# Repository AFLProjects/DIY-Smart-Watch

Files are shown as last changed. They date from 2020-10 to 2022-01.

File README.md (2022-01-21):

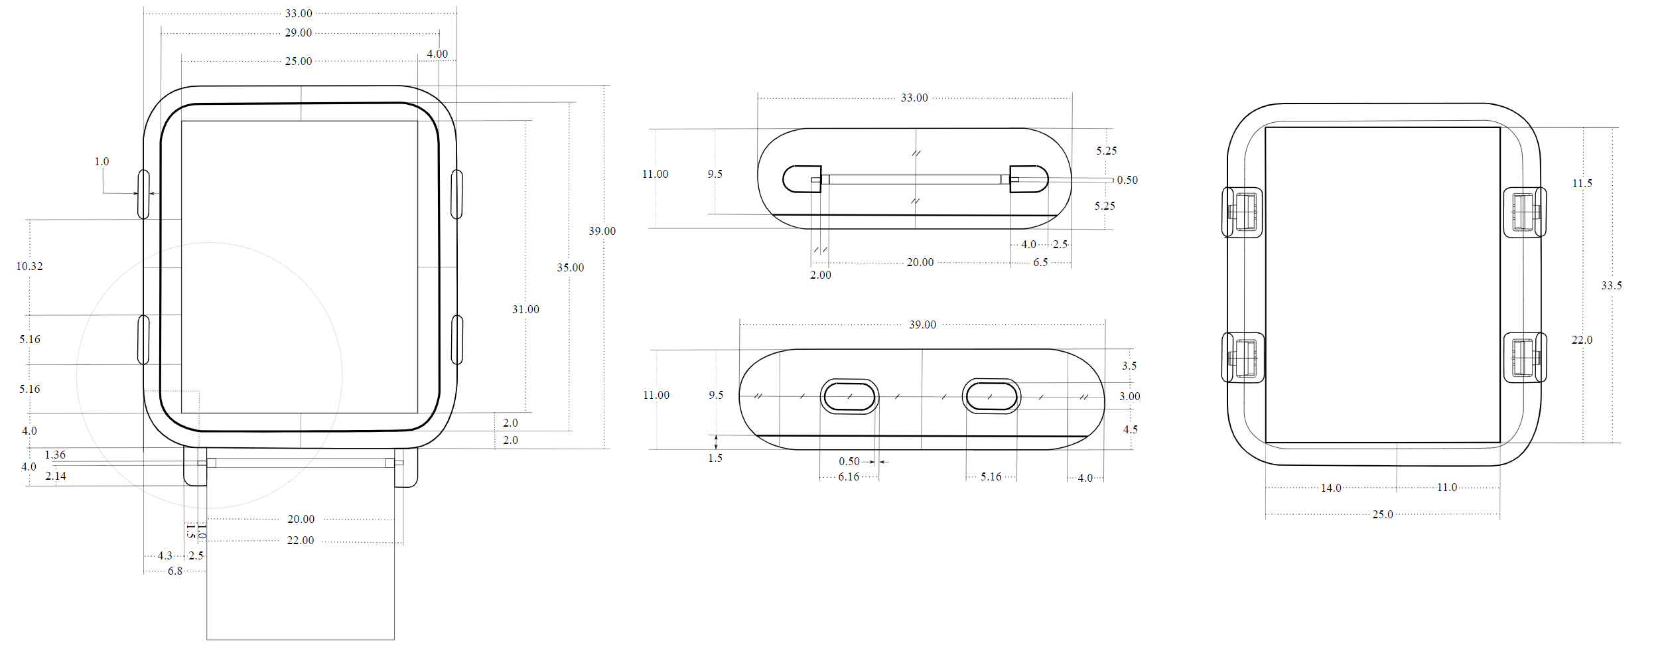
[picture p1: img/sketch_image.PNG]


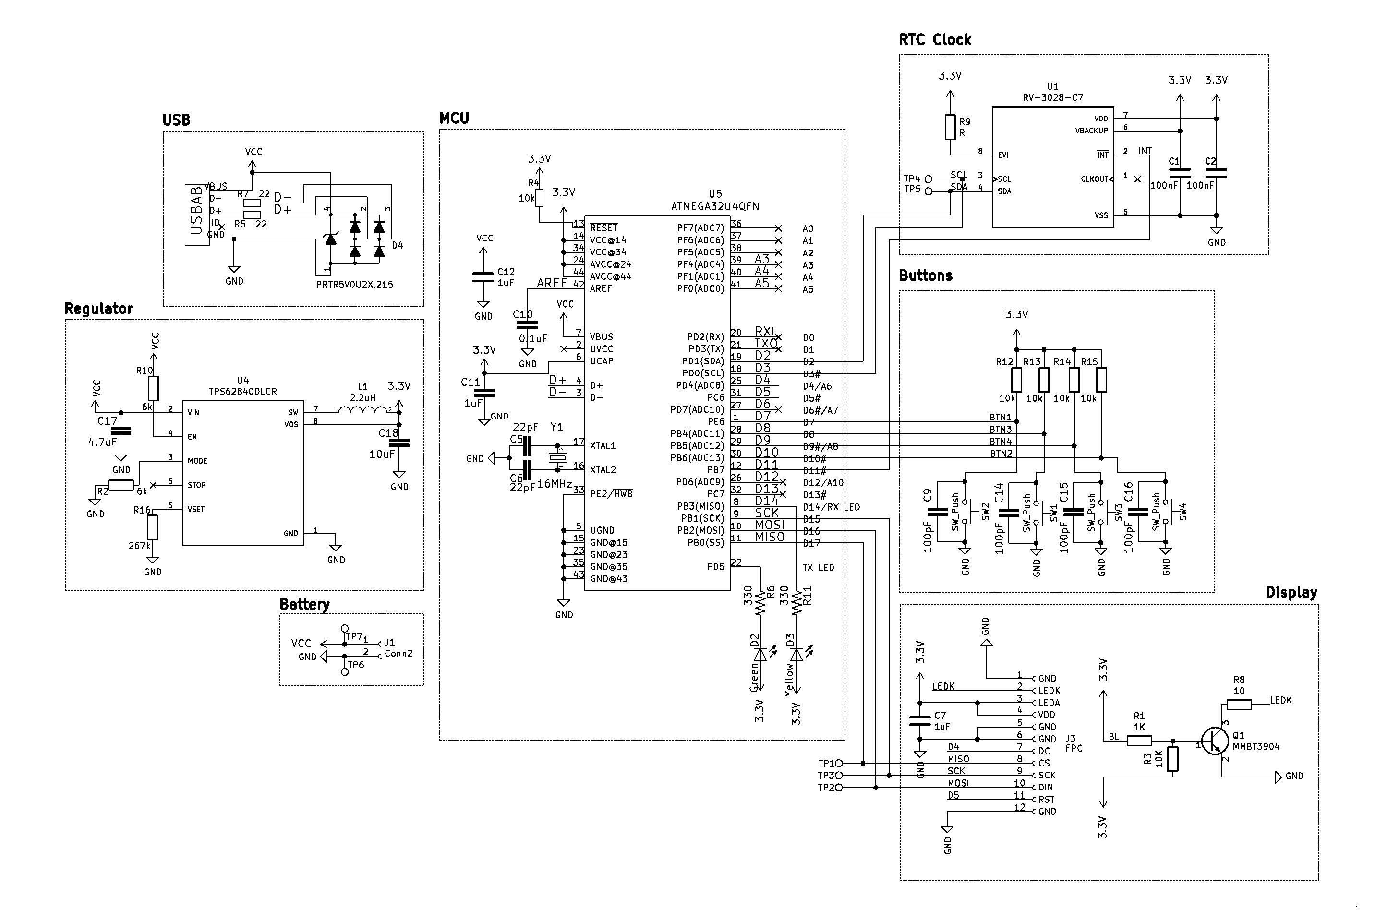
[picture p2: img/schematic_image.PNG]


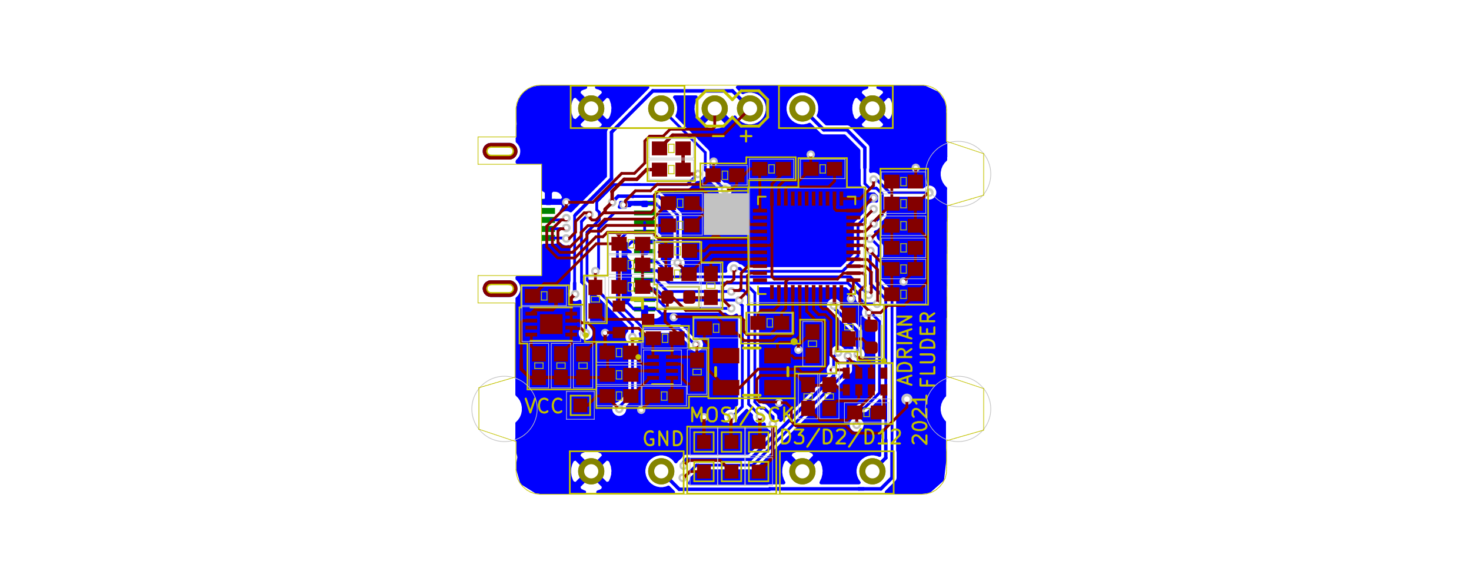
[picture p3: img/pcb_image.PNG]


Project Overview
========

The project is an MCU based smartwatch. The MCU which is used is the [ATMEGA32U4](http://ww1.microchip.com/downloads/en/devicedoc/atmel-7766-8-bit-avr-atmega16u4-32u4_datasheet.pdf). The whole project is powered with the [3.7V 380mAh LQ-S1](https://i.ibb.co/z8Tqzwt/Capture.png) lithium battery.
I am also using an TFT 240 x 240 IPS [ST7789](https://www.rhydolabz.com/documents/33/ST7789.pdf) display with [SPI](https://fr.wikipedia.org/wiki/Serial_Peripheral_Interface). And the [RV-3028-C7](https://www.mouser.fr/datasheet/2/530/RV-3028-C7-1524919.pdf) Extreme Low Power RTC Module with [I2C](https://fr.wikipedia.org/wiki/I2C). In future revisions, an accelerometer will be added.

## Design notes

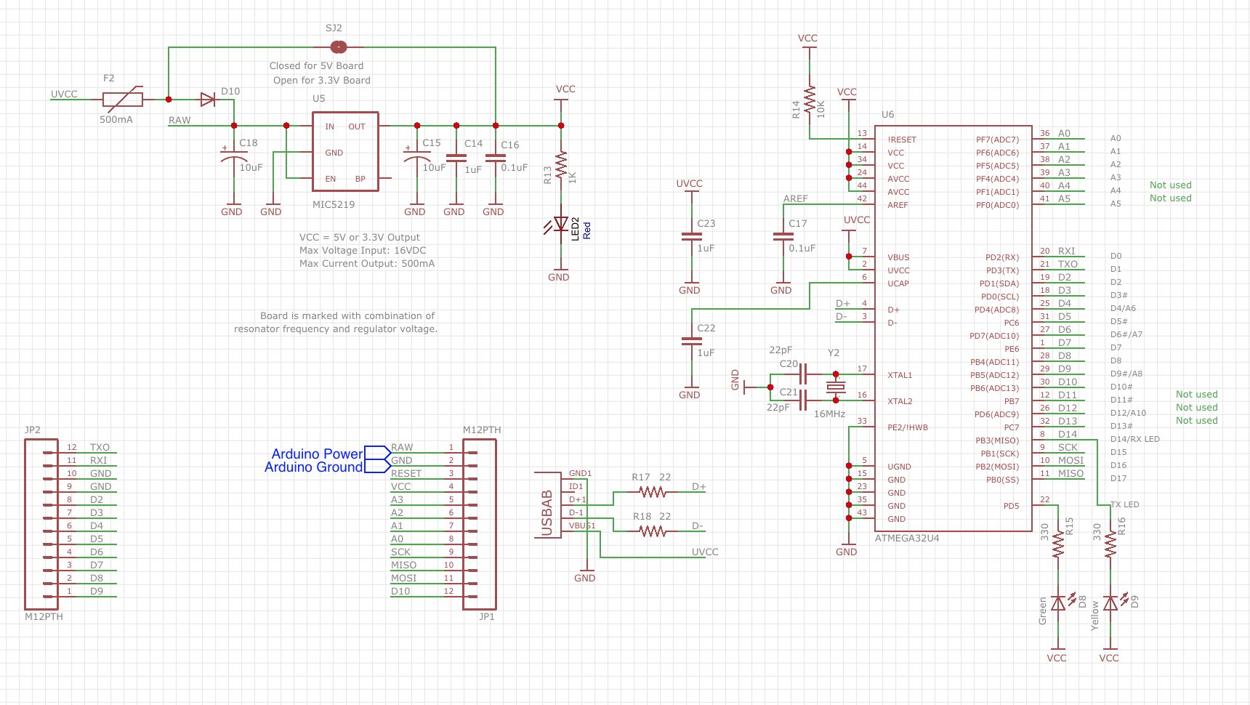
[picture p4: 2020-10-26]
Hardware/Datasheets/ATMEGA32U4/ref/schematic.png

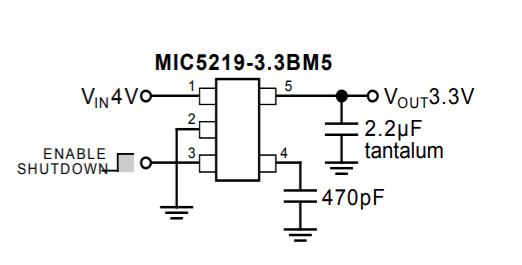
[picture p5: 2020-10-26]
Hardware/Datasheets/MIC5219/ref/schematic.PNG

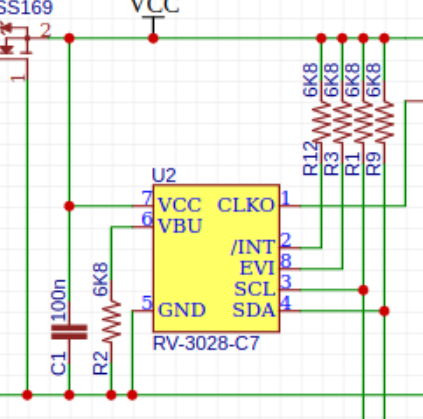
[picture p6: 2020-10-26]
Hardware/Datasheets/RV-3028-C7/ref/schematic.PNG

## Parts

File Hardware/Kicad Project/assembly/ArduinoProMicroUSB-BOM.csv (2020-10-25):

Designator | Quantity | Value | Footprint | LCSC Part #
C3, C7, C11, C12, | 4 | 1uF | Capacitor_SMD:C_0402_1005Metric | C52923
C4, C10, | 2 | 0.1uF | Capacitor_SMD:C_0402_1005Metric | C1525
C5, C6, | 2 | 22pF | Capacitor_SMD:C_0402_1005Metric | C1555
C8, C9, | 2 | 100nF | Capacitor_SMD:C_0402_1005Metric | C1525
D1, | 1 | DIODESOD | Diode_SMD:D_SOD-123 | C8598
D2, | 1 | Green | Diode_SMD:D_0805_2012Metric | C2296
D3, | 1 | Yellow | Diode_SMD:D_0805_2012Metric | C2296
D4, | 1 | D | Diode_SMD:D_0805_2012Metric | C2296
D5, | 1 | LED | Diode_SMD:D_0805_2012Metric | C2296
F1, | 1 | 500mA | Fuse:Fuse_1812_4532Metric | C151168
LED1, | 1 | Red | Diode_SMD:D_0805_2012Metric | C2296
Q1, | 1 | MMBT3904 | Downloads:SOT23-3 | C20526
R1, R2, | 2 | 1K | Resistor_SMD:R_0603_1608Metric | C21190
R3, | 1 | 10K | Resistor_SMD:R_0603_1608Metric | C25804
R4, R12, R13, R14, R15, | 5 | 10k | Resistor_SMD:R_0603_1608Metric | C25804
R5, R7, | 2 | 22 | Resistor_SMD:R_0603_1608Metric | C23345
R6, R10, R11, | 3 | 330 | Resistor_SMD:R_0603_1608Metric | C23138
R8, | 1 | 10 | Resistor_SMD:R_0603_1608Metric | C22859
R9, | 1 | 200 | Resistor_SMD:R_0603_1608Metric | C8218
RN1, RN2, | 2 | R_Pack04 | Resistor_SMD:R_Array_Concave_4x0603 | C66697
U1, | 1 | DS3231M | Package_SO:SOIC-16W_7.5x10.3mm_P1.27mm | C37663
U2, | 1 | MIC5219 | Downloads:SOT23-5 | C145689
U5, | 1 | ATMEGA32U4QFN | Package_QFP:TQFP-44_10x10mm_P0.8mm | C44854
Y1, | 1 | 16MHz | Downloads:CRYSTAL-SMD-5X3.2-4PAD | C16171

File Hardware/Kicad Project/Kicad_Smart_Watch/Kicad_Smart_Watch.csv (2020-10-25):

Source: | F:\Kicad\screentest1\ArduinoProMicroUSB\ArduinoProMicroUSB.sch
Date: | 8/30/2020 4:58:59 PM
Tool: | Eeschema (5.1.6)-1
Generator: | C:\Program Files\KiCad\bin\scripting\plugins/bom_csv_grouped_by_value_with_fp.py
Component Count: | 50
Ref | Qnty | Value | Cmp name | Footprint | Description | Vendor
C1, C2, | 2 | 10uF | CAP_POL1206 | Capacitors:EIA3216
C3, C7, C11, C12, | 4 | 1uF | C | Capacitor_SMD:C_0402_1005Metric | Unpolarized capacitor
C4, C10, | 2 | 0.1uF | CAP0603-CAP | Capacitor_SMD:C_0402_1005Metric
C5, C6, | 2 | 22pF | CAP0603-CAP | Capacitor_SMD:C_0402_1005Metric
C8, C9, | 2 | 100nF | C | Capacitor_SMD:C_0402_1005Metric | Unpolarized capacitor
D1, | 1 | DIODESOD | DIODESOD | Diode_SMD:D_SOD-123
D2, | 1 | Green | LED0603 | Diode_SMD:D_0805_2012Metric
D3, | 1 | Yellow | LED0603 | Diode_SMD:D_0805_2012Metric
D4, | 1 | D | D | Diode_SMD:D_0805_2012Metric | Diode
D5, | 1 | LED | LED | Diode_SMD:D_0805_2012Metric | Light emitting diode
F1, | 1 | 500mA | Fuse_Small | Fuse:Fuse_1812_4532Metric | Fuse, small symbol
J1, | 1 | Battery | Conn_01x02_Female | Connector_PinSocket_2.54mm:PinSocket_1x02_P2.54mm_Vertical | Generic connector, single row, 01x02, script generated (kicad-library-utils/schlib/autogen/connector/)
J3, | 1 | Display FPC | Conn_01x12_Female | Downloads:bearlcd12pin | Generic connector, single row, 01x12, script generated (kicad-library-utils/schlib/autogen/connector/)
LED1, | 1 | Red | LED0603 | Diode_SMD:D_0805_2012Metric
Q1, | 1 | MMBT3904 | MMBT3904 | Downloads:SOT23-3 | 0.2A Ic, 40V Vce, Small Signal NPN Transistor, SOT-23
R1, R2, | 2 | 1K | RESISTOR0603-RES | Resistor_SMD:R_0603_1608Metric
R3, | 1 | 10K | R | Resistor_SMD:R_0603_1608Metric | Resistor
R4, R12, R13, R14, R15, | 5 | 10k | R | Resistor_SMD:R_0603_1608Metric | Resistor
R5, R7, | 2 | 22 | R_Small | Resistor_SMD:R_0603_1608Metric | Resistor, small symbol
R6, R10, R11, | 3 | 330 | RESISTOR0603-RES | Resistor_SMD:R_0603_1608Metric
R8, | 1 | 10 | R | Resistor_SMD:R_0603_1608Metric | Resistor
R9, | 1 | 200 | R | Resistor_SMD:R_0603_1608Metric | Resistor
RN1, RN2, | 2 | R_Pack04 | R_Pack04 | Resistor_SMD:R_Array_Concave_4x0603 | 4 resistor network, parallel topology
SJ1, | 1 | Closed for 5V Board | SOLDERJUMPERNC | Downloads:Jumper
SW1, SW2, SW3, SW4, | 4 | SW_Push | SW_Push | Connector_PinSocket_2.54mm:PinSocket_1x02_P2.54mm_Vertical | Push button switch, generic, two pins
U1, | 1 | DS3231M | DS3231M | Package_SO:SOIC-16W_7.5x10.3mm_P1.27mm | Extremely Accurate I2C-Integrated RTC/TCXO/Crystal SOIC-16
U2, | 1 | MIC5219 | V_REG_LDOSMD | Downloads:SOT23-5
U3, | 1 | USB-AB | USB-AB | Connectors:USB-AB-MICRO-SMD
U4, | 1 | AT24CS32-SSHM | AT24CS32-SSHM | Package_SO:SOIC-8_3.9x4.9mm_P1.27mm | I2C Serial EEPROM, 32Kb (4096x8) with Unique Serial Number, SO8
U5, | 1 | ATMEGA32U4QFN | ATMEGA32U4QFN | Package_QFP:TQFP-44_10x10mm_P0.8mm
Y1, | 1 | 16MHz | CRYSTAL5X3 | Downloads:CRYSTAL-SMD-5X3.2-4PAD

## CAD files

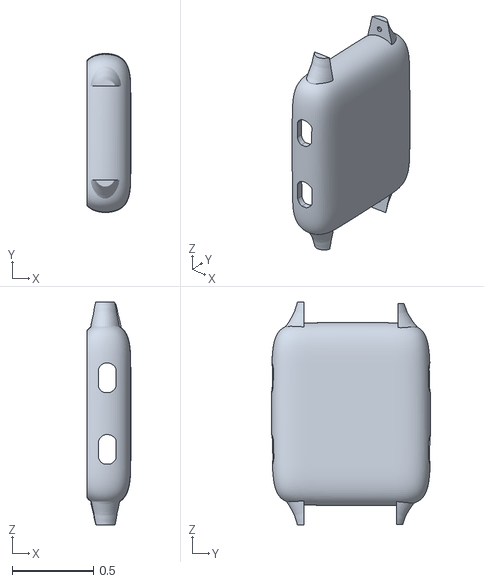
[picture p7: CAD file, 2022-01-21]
Mechanical Design/3D models/smartwatch.stl
0.268 x 0.981 x 1.38

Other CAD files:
Mechanical Design/3D models/smartwatch.blend

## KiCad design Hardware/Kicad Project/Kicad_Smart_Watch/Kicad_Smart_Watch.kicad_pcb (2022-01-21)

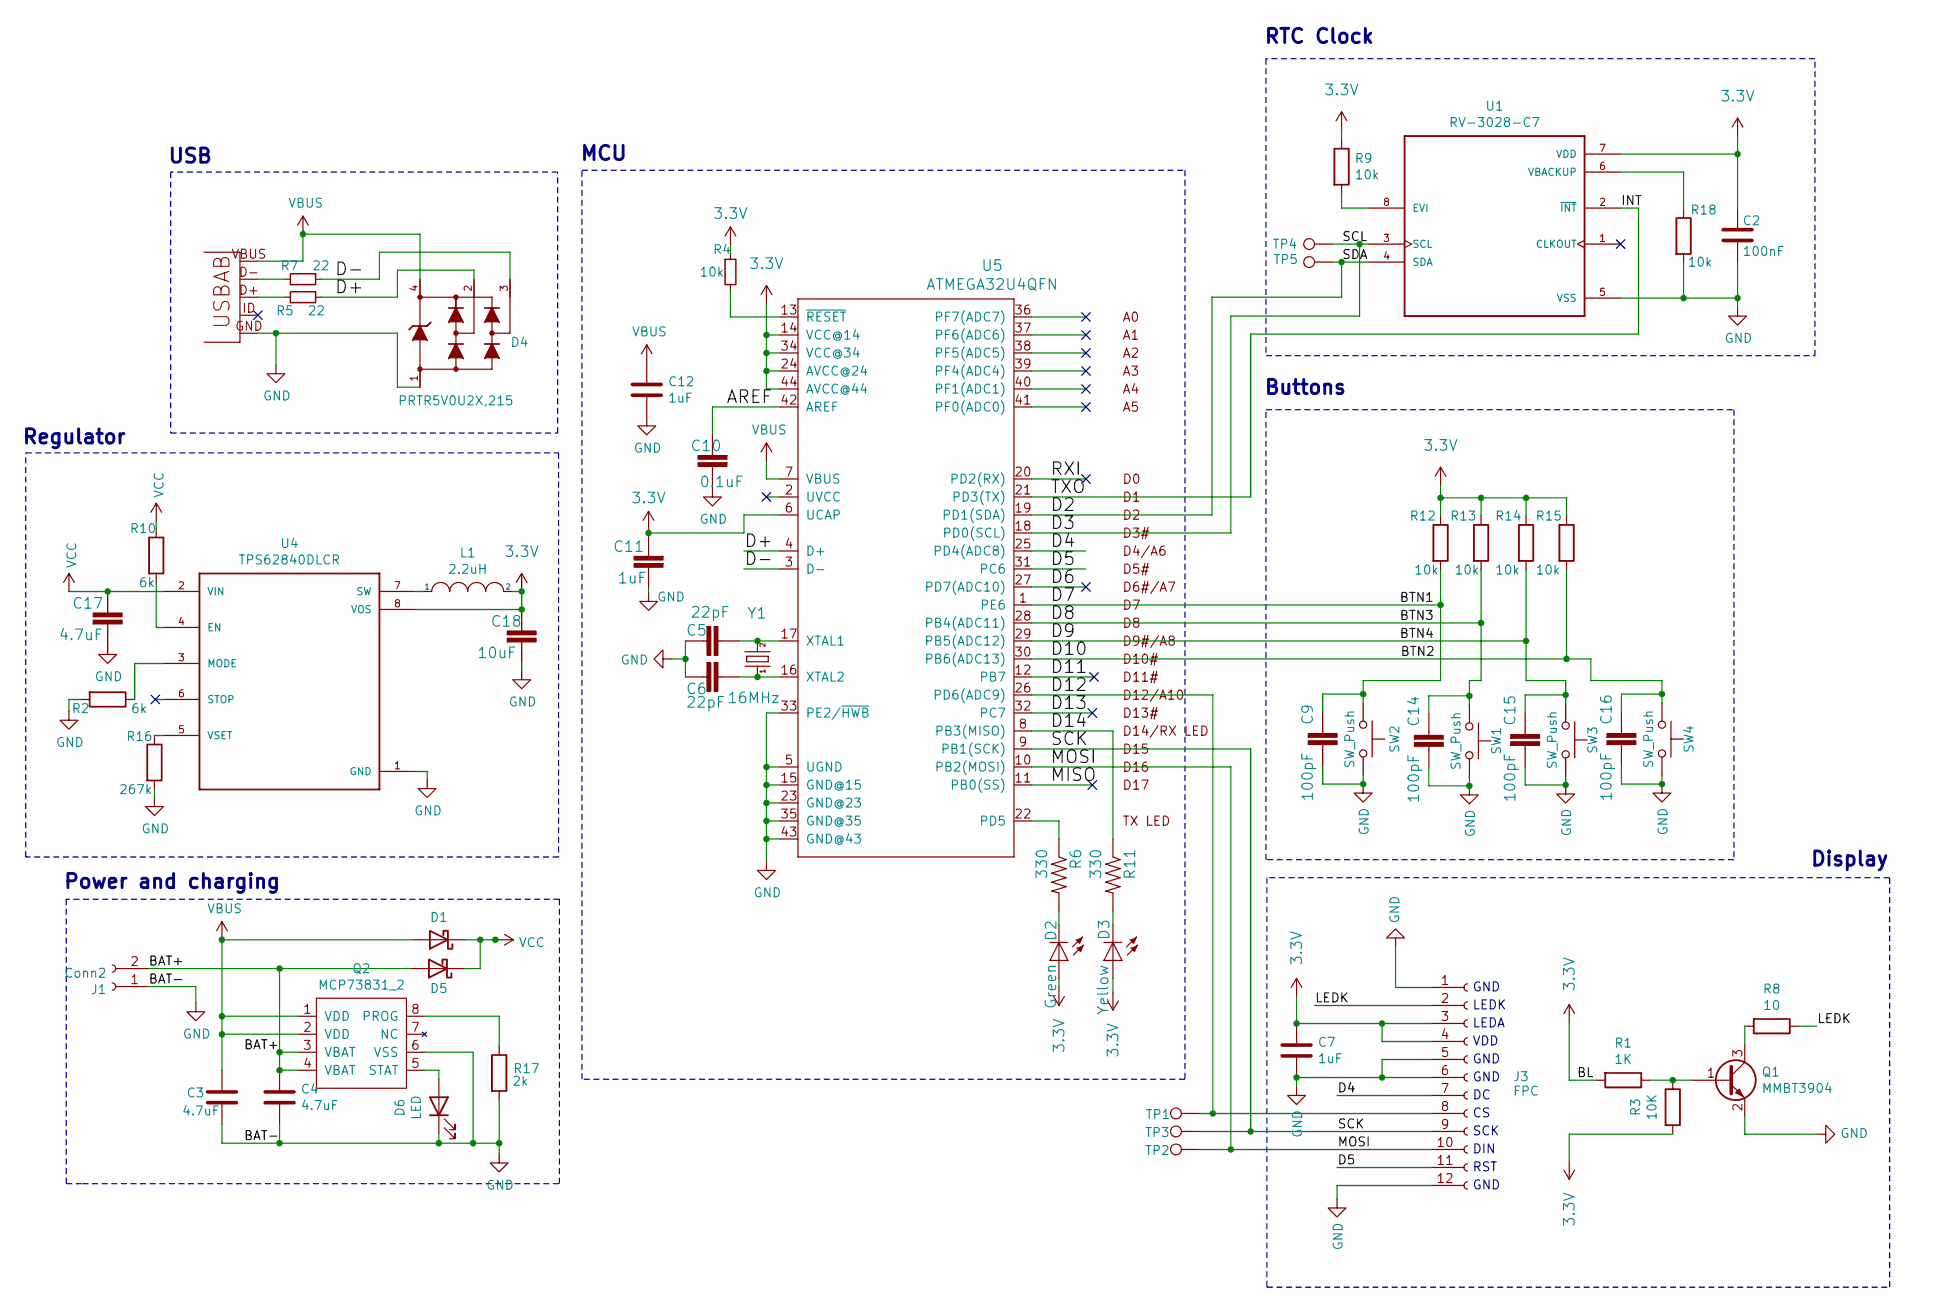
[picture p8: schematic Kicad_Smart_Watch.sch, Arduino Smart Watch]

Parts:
C2: 100nF; 0603
C3, C4, C17: 4.7uF; 0603
C5, C6: 22pF; 0603
C7, C11, C12: 1uF; 0603
C9, C14, C15, C16: 100pF; 0603
C10: 0.1uF; 0603
C18: 10uF; 0603
D1, D5: D_Schottky; 0603
D2: Green; D_0603_1608Metric
D3: Yellow; D_0603_1608Metric
D4: PRTR5V0U2X,215; SOT143B
D6: LED; 0603
J1: Conn2; 1X02
J3: FPC; bearlcd12pin
L1: 2.2uH; 0603
Q1: MMBT3904; SOT23-3
Q2: MCP73831_2; SON50P200X300X100-9N
R1: 1K; 0603
R2, R10: 6k; 0603
R3: 10K; 0603
R4, R9, R12, R13, R14, R15, R18: 10k; 0603
R5, R7: 22; 0603
R6, R11: 330; 0603
R8: 10; 0603
R16: 267k; 0603
R17: 2k; 0603
SW1, SW2, SW3, SW4: SW_Push; 1X02
TP1, TP2, TP3, TP4, TP5: TestPoint; TestPoint_Pad_1.0x1.0mm
U1: RV-3028-C7; IC_RV-3028-C7
U3: USB-AB; GCT_USB3155-XX-X_REVA
U4: TPS62840DLCR; SON50P200X150X100-8N
U5: ATMEGA32U4QFN; QFN50P700X700X100-45N
Y1: 16MHz; CRYSTAL-SMD-5X3.2-4PAD

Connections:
3.3V: C2.1, C7.1, C11.2, C18.1, D2.A, D3.A, J3.3, J3.4, L1.2, R1.2, R3.2, R4.1, R9.1, R12.1, R13.1, R14.1, R15.1, U1.7 (VDD), U4.8 (VOS), U5.6 (UCAP), U5.14 (VCC@14), U5.24 (AVCC@24), U5.34 (VCC@34), U5.44 (AVCC@44)
/AREF: C10.2, U5.42 (AREF)
/BAT+: C4.1, D5.2 (A), J1.2, Q2.3 (VBAT), Q2.4 (VBAT)
/BTN1: C9.1, R12.2, SW2.1, U5.1 (PE6)
/BTN2: C16.1, R15.2, SW4.1, U5.30 (PB6(ADC13))
/BTN3: C14.1, R13.2, SW1.1, U5.28 (PB4(ADC11))
/BTN4: C15.1, R14.2, SW3.1, U5.29 (PB5(ADC12))
/D2: TP5.1, U1.4 (SDA), U5.19 (PD1(SDA))
/D3: TP4.1, U1.3 (SCL), U5.18 (PD0(SCL))
/D4: J3.7, U5.25 (PD4(ADC8))
/D5: J3.11, U5.31 (PC6)
/D6: U5.27 (PD7(ADC10))
/D11: U5.12 (PB7)
/D12: J3.8, TP1.1, U5.26 (PD6(ADC9))
/D13: U5.32 (PC7)
/D14: R11.1, U5.8 (PB3(MISO))
/D+: D4.2, R7.1, U5.4 (D+)
/D-: D4.3, R5.1, U5.3 (D-)
/INT: U1.2 (~INT~), U5.21 (PD3(TX))
/LEDK: J3.2, R8.1
/MISO: U5.11 (PB0(SS))
/MOSI: J3.10, TP2.1, U5.10 (PB2(MOSI))
/RXI: U5.20 (PD2(RX))
/SCK: J3.9, TP3.1, U5.9 (PB1(SCK))
GND: C2.2, C3.2, C4.2, C5.2, C6.2, C7.2, C9.2, C10.1, C11.1, C12.2, C14.2, C15.2, C16.2, C17.2, C18.2, D4.1, D6.1 (K), J1.1, J3.1, J3.5, J3.6, J3.12, Q1.2 (E), Q2.6 (VSS), R2.2, R16.2, R17.2, R18.2, SW1.2, SW2.2, SW3.2, SW4.2, U1.5 (VSS), U3.GND, U4.1 (GND), U5.5 (UGND), U5.15 (GND@15), U5.23 (GND@23), U5.33 (PE2/~HWB), U5.35 (GND@35), U5.43 (GND@43); also elsewhere on the board
unnamed: C5.1, U5.17 (XTAL1), Y1.3 (2)
unnamed: C6.1, U5.16 (XTAL2), Y1.1
unnamed: D2.C, R6.2
unnamed: D3.C, R11.2
unnamed: D6.2 (A), Q2.5 (STAT)
unnamed: L1.1, U4.7 (SW)
unnamed: Q1.1 (B), R1.1, R3.1
unnamed: Q1.3 (C), R8.2
unnamed: Q2.8 (PROG), R17.1
unnamed: R2.1, U4.3 (MODE)
unnamed: R4.2, U5.13 (~RESET)
unnamed: R5.2, U3.D-
unnamed: R6.1, U5.22 (PD5)
unnamed: R7.2, U3.D+
unnamed: R9.2, U1.8 (EVI)
unnamed: R10.2, U4.4 (EN)
unnamed: R16.1, U4.5 (VSET)
unnamed: R18.1, U1.6 (VBACKUP)
VBUS: C3.1, C12.1, D1.2 (A), D4.4, Q2.1 (VDD), Q2.2 (VDD), U3.VBUS, U5.7 (VBUS)
VCC: C17.1, D1.1 (K), D5.1 (K), R10.1, U4.2 (VIN); also elsewhere on the board

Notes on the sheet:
USB
RTC Clock
Display
LEDK
LEDA
VDD
GND
SCK
DIN
RST
Buttons
MCU
Regulator
Power and charging

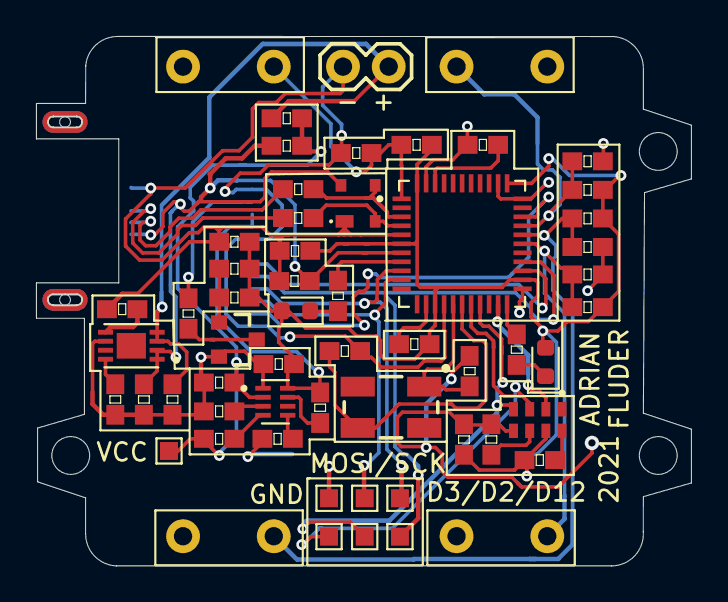
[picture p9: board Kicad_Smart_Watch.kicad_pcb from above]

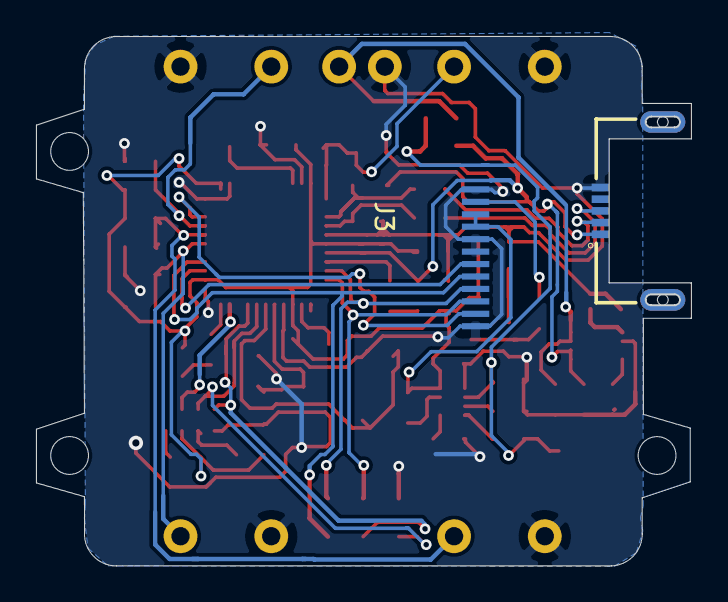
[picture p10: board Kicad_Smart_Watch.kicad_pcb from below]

Board: 2 copper layers, 36.4 x 29.4 mm, 60 parts (2 on the bottom side), 40 nets.

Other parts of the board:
GND: TestPoint; TestPoint_Pad_1.0x1.0mm
VCC: TestPoint; TestPoint_Pad_1.0x1.0mm

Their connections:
GND: GND.1; also elsewhere on the board
VCC: VCC.1; also elsewhere on the board

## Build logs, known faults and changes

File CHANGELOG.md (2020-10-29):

28/10/2020 -> rev 0.3

Schematics:
- run ERC!

- add ESD protection diode on USB data/power lines (https://fr.farnell.com/nexperia/prtr5v0u2x-215/diode-double-tvssot-143b/dp/1524157?st=PRTR5V0U2X) or similar

- add small debouncing caps (100pF-100nF) on the switches (parallel to the PBs)

- MIC5129 is a linear regulator, so it will dissipate a lot of power. Consider using a proper PMIC (power management IC) with built-in buck/SEPIC converter (high efficiency) and battery charger.

- if the Atmega is powered from 3.3V from an external regulator, you should use a different connection of VBus/UVCC/VCC pins (see datasheet Figure 21-6.)

- D1 has too much dropout (I assume it's silicon diode - 0.6 to 0.7V) for the regulator to provide +3.3V from battery power (+3.7V typical for li-ion cells). Choose a schottky diode or a FET-based reverse polarity protection circuit (google: 'mosfet reverse polarity protection', just make sure the diode has low enough dropout and the transistor - low emough VGS(on) to work from 5V).

- SHLD pads in typical USB connectors should be connected to the GND.

- Schematic is not consistent with the PCB. Where are the switches?

29/10/2020

-Fixed most of ERC warnings

-Added ESD protection on USB data lines.

-Added debouncing capacitors on the switches

-Found new voltage regulator : https://www.mouser.fr/ProductDetail/Maxim-Integrated/MAX20049ATEF-VY+?qs=%252B6g0mu59x7LRpRI5UmmoVA==

-Fixed the MCU power connections

https://www.mouser.fr/ProductDetail/Nexperia/PRTR5V0U2X215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

https://www.mouser.fr/datasheet/2/916/PRTR5V0U2X-1320589.pdf

https://www.snapeda.com/parts/PRTR5V0U2X%2C215/Nexperia%20USA/view-part/?ref=search&t=PRTR5V0U2X,215

https://www.mouser.fr/ProductDetail/Maxim-Integrated/MAX20049ATEF-VY+?qs=%252B6g0mu59x7LRpRI5UmmoVA==

https://www.mouser.fr/datasheet/2/256/MAX20049-1622801.pdf

-Connected USB SHLD pads to GND 

Remaining tasks :

-Finish ERC

-Connect the new regulator

-Add switches t PCB

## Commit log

2020-10-26 added reference schematics
2020-10-26 added schematic preview
2020-10-27 rev 0.1
    [ArduinoProMicroUSB.kicad_pcb, ArduinoProMicroUSB.sch]
2020-10-27 rev 0.2
    [ArduinoProMicroUSB.kicad_pcb]
2020-10-28 schematic checking
    [ArduinoProMicroUSB.sch]
2020-10-28 rev 0,2
    [ArduinoProMicroUSB.sch]
2020-10-28 rev 0.3
    [ArduinoProMicroUSB-B_Cu.gbr, ArduinoProMicroUSB-B_Mask.gbr, ArduinoProMicroUSB-B_Paste.gbr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]
2020-10-29 updated schematic
    [ArduinoProMicroUSB.kicad_pcb, ArduinoProMicroUSB.sch]
2020-10-30 schematic pdf
2020-10-31 rev 0.4
    [ArduinoProMicroUSB.kicad_pcb, ArduinoProMicroUSB.sch, ArduinoProMicroUSB_old.kicad_pcb]
2020-11-02 working on pcb
    [ArduinoProMicroUSB.kicad_pcb, ArduinoProMicroUSB.sch]
2020-11-04 finishing hardware design
    [ArduinoProMicroUSB-B_Cu.gbr, ArduinoProMicroUSB-B_Mask.gbr, ArduinoProMicroUSB-B_Paste.gbr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]
2020-11-04 updated pcb img
2020-11-04 updated pcb
    [ArduinoProMicroUSB.kicad_pcb]
2020-11-06 checking schematic
    [ArduinoProMicroUSB.sch]
2020-11-06 pcb checking
    [ArduinoProMicroUSB.kicad_pcb]
2020-11-07 checking pcb
    [ArduinoProMicroUSB-B_Cu.gbr, ArduinoProMicroUSB-B_Mask.gbr, ArduinoProMicroUSB-B_Paste.gbr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]
2020-11-17 3d print photos
2020-11-18 Added 3d models
    [smartwatch.blend, smartwatch.stl]
2020-11-18 updated 3d model
    [smartwatch.blend, smartwatch.stl]
2020-11-18 3D model updated
    [smartwatch.blend, smartwatch.stl]
2020-11-23 updated project name
    [ArduinoProMicroUSB-B_Cu.gbr, ArduinoProMicroUSB-B_Mask.gbr, ArduinoProMicroUSB-B_Paste.gbr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]
2020-12-06 updated mcu board pcb
    [Kicad_Smart_Watch-B_Cu.gbr, Kicad_Smart_Watch-B_Mask.gbr, Kicad_Smart_Watch-B_Paste.gbr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]
2022-01-21 project continuation
    [Kicad_Smart_Watch.kicad_pcb]
